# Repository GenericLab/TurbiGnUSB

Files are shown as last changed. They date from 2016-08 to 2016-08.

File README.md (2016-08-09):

# TurbiGnUSB

Good Old times.. 5 years of geeking around with turbidity meters. Read an overview here: http://hackteria.org/projects/turbidity-meter/

And more notes about Kresse-Shields, KafiSchnapps detektors, Daphnia2Midi controllers and more: http://hackteria.org/wiki/DIY_turbidity_meters

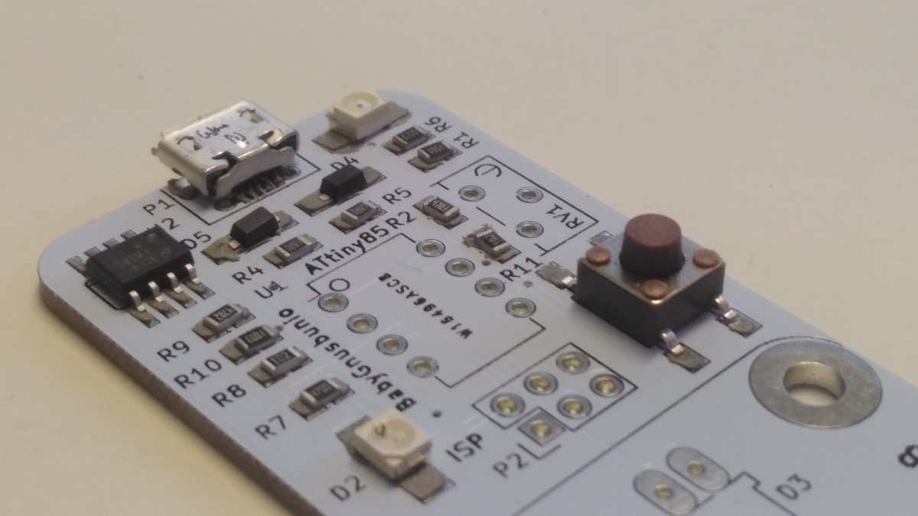
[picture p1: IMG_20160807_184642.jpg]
TurbiSiech


If you want to reprogram the attiny, use the bootloader developed by anyma and iyok.

https://github.com/TeenyRiot

# Build it!

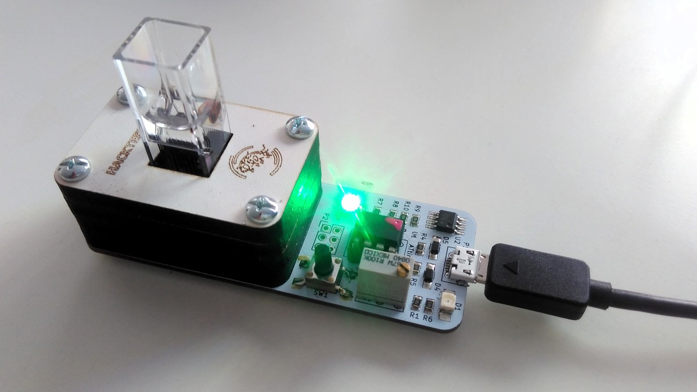
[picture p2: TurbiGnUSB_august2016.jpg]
TurbiSiech final


# Calibrati it!

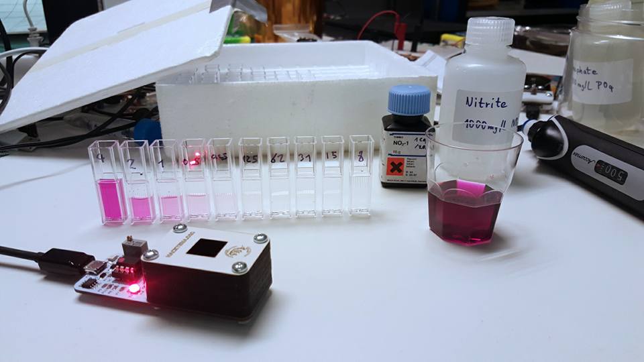
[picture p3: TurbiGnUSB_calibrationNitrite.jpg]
TurbiSiech calibration


# Use it! 

The TurbiGnUSB is detected as a keyboard. The LED inside the optical chamber is always on. press the button and the device starts typing the value into your laptop, use a spreadsheet or notepad to record the measurements.

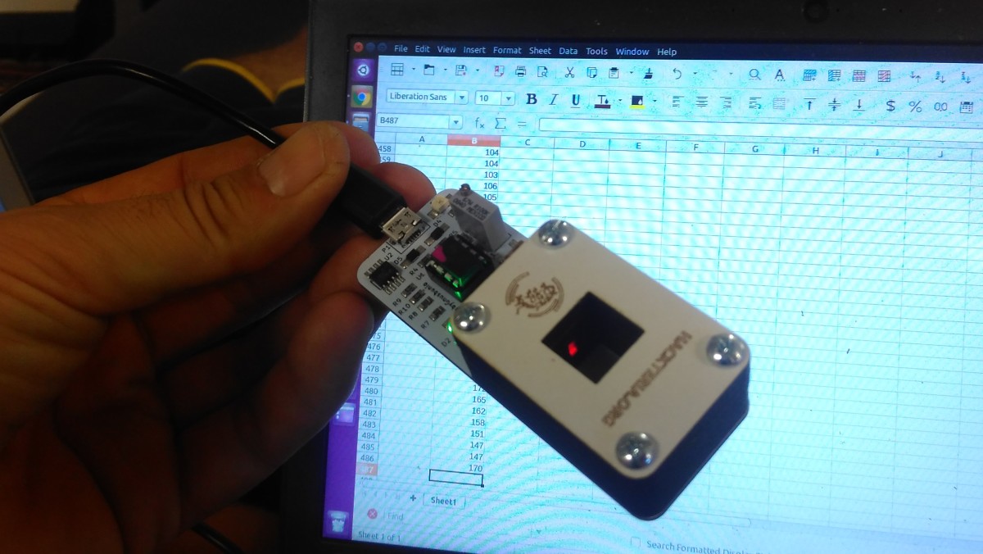
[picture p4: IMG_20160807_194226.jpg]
TurbiSiech as Keyboard


# What you need

* Cuvettes (plastic)
* some colorimetric test
* choose the right LED color for your test
* time

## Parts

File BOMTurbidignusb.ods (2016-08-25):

TurbidityGnUSB Partlist
10.8.2016
Reference | Value | Footprint | Mouser Part
U1 | ATTINY85-P | DIP-8_W7.62mm | 556-ATTINY85-20PU
U2 | LM385, 2.5V | SO08 | 926-LM385MX/NOPB |  |  |  |  | not the 1.2 or 2.5 V fixed ones | LM385DR-2-5
D1 | LED | TopLed Red | 720-LST670-K1L2-1-Z
D2 | LED | TopLed Green | 720-LGT670K1L21Z
D3 | LED | 5mm LED | 859-LTL-10224W
D4 | 3.3V | SMD 1206 / SOD-123 | 821-BZT52B3V3 | ← maybe this | Wrong Zener? |  |  | does not work → | 621-MMSZ5226B-F | or this 3.6V → | 821-BZT52B3V6
D5 | 3.3V | SMD 1206 / SOD-123 | 821-BZT52B3V3 | ← maybe this |  |  |  | does not work → | 621-MMSZ5226B-F
P1 | USB_OTG | Connector USB_Micro-B | 649-10118194-0001LF | ← with pins |  | without-> | 649-10118192-0001LF
R1 | 1.5k | SMD 805
R2 | 470k | SMD 805
R3 | LDR | LDR with leads | ebay
R4 | 68 Ohm | SMD 805
R5 | 68 Ohm | SMD 805
R6 | 820 Ohm | SMD 805
R7 | 1k | SMD 805
R8 | 1k | SMD 805
R9 | 47k | SMD 805
R10 | 100k | SMD 805
R11 | 1k | SMD 805
RV1 | 100k | Trimmer-Potentiometer_ScrewUp |  | 64W-100K | 64W-500K
SW1 | SW_PUSH_SMALL_H | PUSH_BUTTON_SMD | 693-1301.9319
P2 | CONN_02X03 | Pin_Headers:Pin_Header_Straight_2x03
Socket |  | DIL8

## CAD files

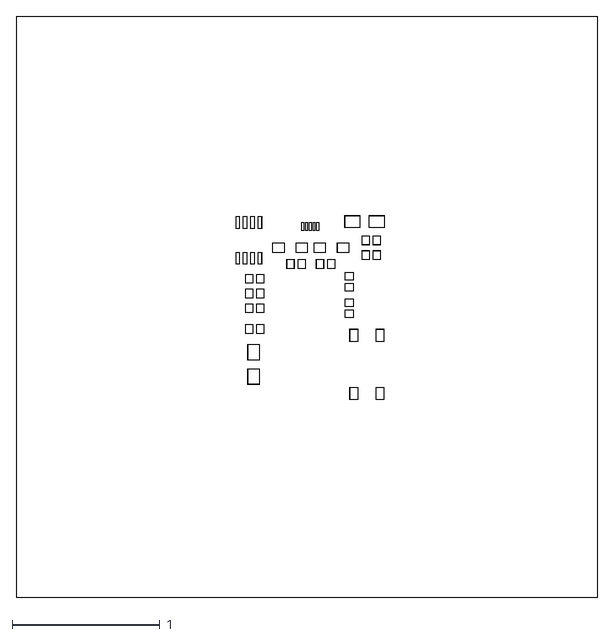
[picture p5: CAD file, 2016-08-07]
TurbidiGnUSB_PCB/GERBERTurbidity/TurbidignusbF.dxf
3.94 x 3.94

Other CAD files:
LaserFiles/TurbidityGnUSB_laser.DWG
LaserFiles/TurbidityGnUSB_laser.SLDDRW
TurbidiGnUSB_PCB/GERBERTurbidity/Turbidignusb-F.Paste.dxf

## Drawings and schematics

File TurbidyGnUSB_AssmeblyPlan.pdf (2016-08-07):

# Assembly Plan

# TurbidityGnUSB

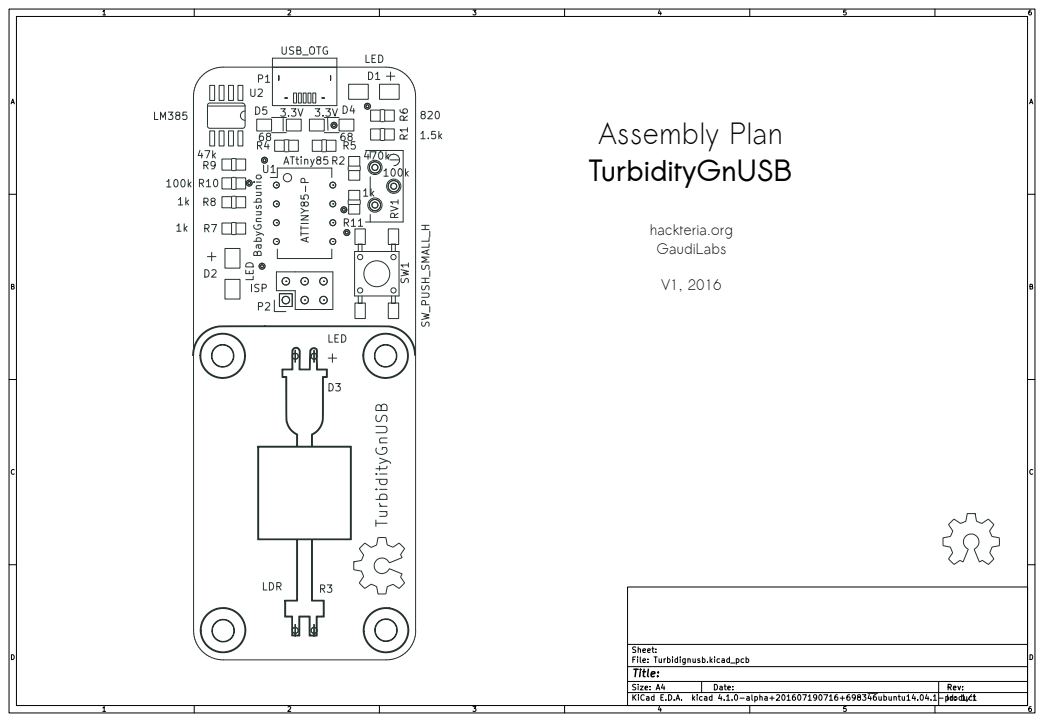
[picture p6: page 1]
hackteria.org GaudiLabs

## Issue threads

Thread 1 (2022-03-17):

Can I use it to measure turbidity in a PVC tube in real time?

cheesealmighty, 2022-03-17:
I'm a neurosurgery resident in Turkey. We are working on a system that will measure CSF density and content in real time.

We want to measure turbidity of the otherwise clear CSF that flows through the closed yet transparent line. So that we can see if the cell count/protein content of the fluid is increasing. Would it possible for us to modify the test chamber so that rather than a rectangular cuvette, a fluid line enters the measurement chamber and exits without interruption. We are thinking of an opaque chamber that forms an "U" so it can be dark inside for the measurement?

This is the device we're using for the CSF drainage: http://www.medtronic.me/content/dam/medtronic-com/products/neurological/critical-care/mns-duetqrg.pdf

And would it be possible to differentiate what is causing the turbidity increase? As in, can we guess whether leukocytes or the erythrocytes increasing? And can we check if the glucose or protein levels are increasing within the CSF?

dusjagr, 2022-03-17:
Interesting application!
Definately worth to look deeper into it, using open science hardware approches.
Feel free to post your interest to this forum too:
https://forum.openhardware.science/

our turbidity meter is more of do-it-yourself educational device, far from being used in a medical setting with real patients.

cheesealmighty, 2022-03-24:
As long as it can give reliable measurements, it can be refined later. This is more of a experimental device. Practically, it isn't much different from taking photos of the translucent tube/collection chamber.

Thanks I'll try that site as well.

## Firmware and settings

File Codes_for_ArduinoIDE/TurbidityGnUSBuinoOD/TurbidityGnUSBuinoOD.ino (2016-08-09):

#include "CocoKeyboard.h"

//cocokeyboard Turbidity Measurement


float sensorValue=0;
float refValue=0;

int buttonState = 0;         // variable for reading the pushbutton status

const int analogInPin = A2;  // Analog input pin that the potentiometer is attached to
const int buttonPin = 2;     // the number of the pushbutton pin
const int SensorLEDPin = 1;     // the number of the pushbutton pin
const int LEDPin = 0;     // the number of the pushbutton pin


void setup() {
  
    pinMode(buttonPin, INPUT);
    digitalWrite(buttonPin, HIGH);
    pinMode(SensorLEDPin, OUTPUT);
    pinMode(LEDPin, OUTPUT);

    digitalWrite(SensorLEDPin, LOW);   // turn the LED on (HIGH is the voltage level)

  
  // don't need to set anything up to use CocoKeyboard
}


void loop() {
  

  buttonState = digitalRead(buttonPin);

    if (buttonState == LOW) {

    digitalWrite(LEDPin, HIGH);   // turn the LED on (HIGH is the voltage level)

    sensorValue = analogRead(analogInPin);


  // Type out this string letter by letter on the computer (assumes US-style
  // keyboard)
  
  if (refValue==0)
  CocoKeyboard.println(sensorValue); else CocoKeyboard.println(log10(refValue/(1024-sensorValue))); 
  
  
  // It's better to use CocoKeyboard.delay() over the regular Arduino delay()
  // if doing keyboard stuff because it keeps talking to the computer to make
  // sure the computer knows the keyboard is alive and connected
  CocoKeyboard.delay(200);
  
  buttonState = digitalRead(buttonPin);
  if (buttonState == LOW)   
  {refValue = 1024-analogRead(analogInPin);

  while(buttonState==LOW) buttonState = digitalRead(buttonPin);
  }
  
  digitalWrite(LEDPin, LOW);   // turn the LED on (HIGH is the voltage level)

    }
}

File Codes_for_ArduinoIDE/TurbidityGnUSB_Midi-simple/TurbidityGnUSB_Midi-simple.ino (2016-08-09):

/*---------------------------------------------------------------------------------------------

  Coco MIDI Library 2012 by Michael Egger and update 2016 by Iyok
  install the Coconut from https://cocomake7.github.io/

  The following code is for use with the TurbdityGnUSB, a photometer/turbidity meter.
  see more: https://github.com/GenericLab/TurbiGnUSB
  
 */
 
#include <CocoMidi.h>
MIDIMessage midimsg;

const int SensorLEDPin = 1;    //the LED inside the TurbiGnUSB is on when the pin is LOW
const int LEDonBoardPin = 0;
const int sensorPin = A2;

int averaging = 1; //used to be 4
int measuringON = 1;

int averagingDelay = 8; //used to be 40
int sample_delay = 8; //used to be 1000
int MIDI_delay = 4;

int LEDstate = 1;
long sensorValue = 0;         // variable to store the value coming from the sensor
int sensorValueTMP = 0;
uint8_t sensorValueHB = 0;         // HighByte for seperating the midi-message
uint8_t sensorValueLB = 0;         // LowByte for seperating the midi-message

void usb_poll()
{
    usbPoll();
}

void setup() {
    CocoMidi.init();
    
    pinMode (SensorLEDPin, OUTPUT);
    pinMode (LEDonBoardPin, OUTPUT);
    
    digitalWrite(SensorLEDPin,1);              // Blink a bit to show that it's ready
    digitalWrite(LEDonBoardPin,1);
    CocoMidi.delay(100);
    digitalWrite(SensorLEDPin,0);
    digitalWrite(LEDonBoardPin,0);
    CocoMidi.delay(100);
    digitalWrite(SensorLEDPin,1);
    digitalWrite(LEDonBoardPin,1);
    CocoMidi.delay(100);
    digitalWrite(SensorLEDPin,0);
    digitalWrite(LEDonBoardPin,0);
    CocoMidi.delay(100);
    digitalWrite(SensorLEDPin,1);
    CocoMidi.delay(100);
}


void loop() {
  
  sensorValue = 0;
  sensorValueTMP = analogRead(sensorPin);
  
  if (measuringON) {
    for(int c = 0 ; c < averaging; c +=1) { 
      digitalWrite(SensorLEDPin,!LEDstate);
      digitalWrite(LEDonBoardPin,LEDstate);
      CocoMidi.delay(averagingDelay);
      sensorValueTMP = analogRead(sensorPin);   // analogRead returns 0-1023
      sensorValue = sensorValue + sensorValueTMP;
      digitalWrite(SensorLEDPin,1);
      digitalWrite(LEDonBoardPin,0);
      CocoMidi.delay(averagingDelay);
    }
  
  digitalWrite(SensorLEDPin,1);
  sensorValue = sensorValue / (averaging);
  
  sensorValueHB = sensorValue >> 3;
  sensorValueLB = sensorValue & 0x7;

        CocoMidi.send(MIDI_CONTROLCHANGE,1,sensorValueHB);     // put new control change message into MIDI sending queue
        CocoMidi.delay(MIDI_delay);
        
        CocoMidi.send(MIDI_CONTROLCHANGE,2,sensorValueLB);     // put new control change message into MIDI sending queue
        CocoMidi.delay(MIDI_delay);              // give some time for sending, otherwhise the MIDI queue could fill up
  
  }      

  if (CocoMidi.read(&midimsg)) {
      
        switch(midimsg.command) {
                      
            case MIDI_CONTROLCHANGE: 
               switch(midimsg.key) {
                 case 0:
                   LEDstate = midimsg.value;
                   break;
                 
                 case 1:
                   averaging = midimsg.value;
                   break;  
                 
                 case 2: 
                   averagingDelay = (midimsg.value); 
                   break;                       
                 
                 case 3:
                   sample_delay = (midimsg.value * 50);
                   break;
                   
                 case 10:
                   measuringON = midimsg.value; 
                   break;
 
               }
        }
    }
   
   if (sample_delay > (averaging * 2 * averagingDelay)) {
     CocoMidi.delay(sample_delay - (averaging * 2 * averagingDelay));
   }
   
   CocoMidi.update();
   CocoMidi.delay(1);

}

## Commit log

2016-08-07 KiCad design files for PCB
    V1.0
    [Turbidignusb-F.Paste.dxf, Turbidignusb.sch, TurbidignusbF.dxf]
2016-08-07 Added laser files for sensor holder
    so
    [TurbidityGnUSB_laser.DWG, TurbidityGnUSB_laser.SLDDRW]
2016-08-07 Added Assembly Plan
2016-08-09 adding Arduino code
2016-08-12 Added BOM
    [BOMTurbidignusb.ods]
2016-08-25 Made some important corrections in the Bill of Materials
    [BOMTurbidignusb.ods]
